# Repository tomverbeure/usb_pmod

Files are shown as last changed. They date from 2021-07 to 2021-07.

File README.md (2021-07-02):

# USB Combo PMOD

It's common to implement Full Speed or Low Speed (FS/LS) USB host or device controllers
on an FPGA by just using their digital IOs, configured as 3V3 LVCMOS. 

A good example is the [TinyFPGA BX board](https://www.adafruit.com/product/4038), 
which comes by default with a hardware-only USB device controller that's used to program new bitstreams into flash. 

Another one is [Fomu](https://www.crowdsupply.com/sutajio-kosagi/fomu), another FPGA development
board that's about as tiny as the USB Type-A connector itself.

However, on FPGAs such as those from the MAX10 family, this solution doesn't work: at
3V3, their IOs don't have the required driving strength. (Only 2mA for a 3V3 LVCMOS IO
on a MAX10.)

For those cases, the easiest FS/LS solution is to use an 
[STUSB03E PHY](https://www.st.com/en/interfaces-and-transceivers/stusb03e.html) for USB host or USB device.
It's a tiny little chip that translates regular digital signals as low as 1.6V to 
USB standard compliant signaling levels.

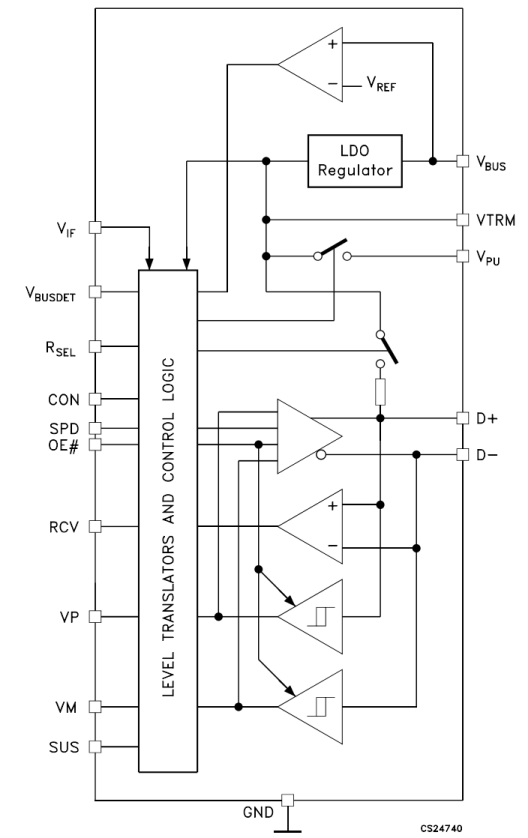
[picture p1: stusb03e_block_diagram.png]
STUSB03E Block Diagram


This project is a PMOD compatible module that contains an STUSB03E, 
the necessary passive components around it, as well as a USB Type-A or
USB Type-B connector footprint.

You need to decide up front whether to use PMOD for USB host or device
purposes, and change the soldered components accordingly.

It's a 4-layer PCB which is overkill, but there's currently no cost difference between
2 and 4 layer PCBs at [JLCPCB](https://jlcpcb.com), so I didn't spend any time to make
it work with 2 layers. It's definitely doable though!

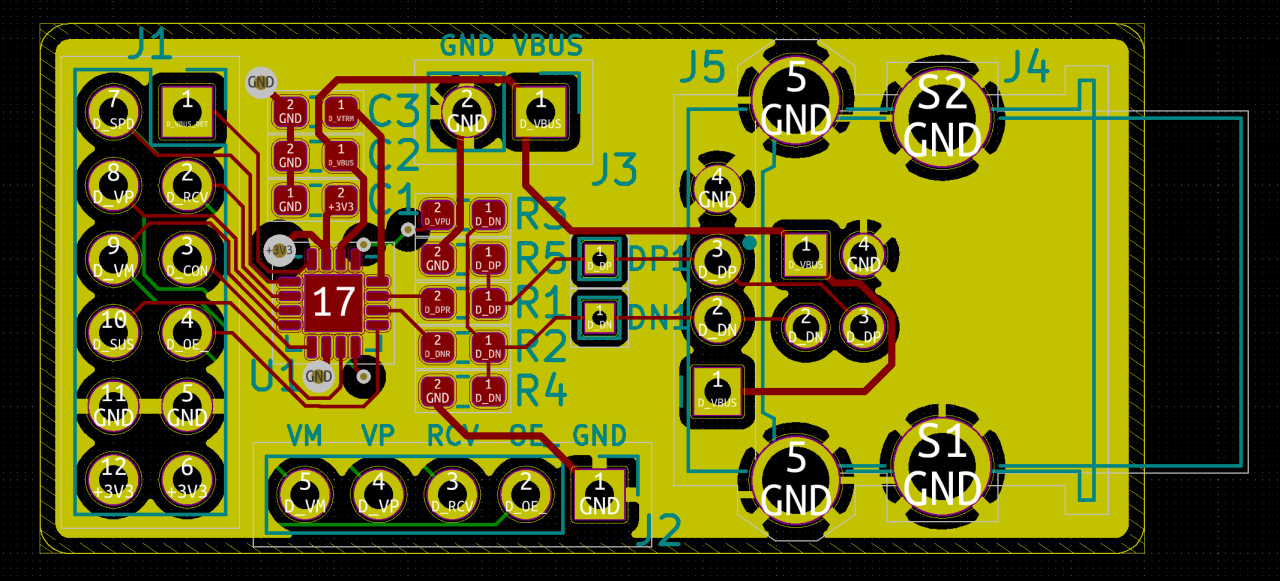
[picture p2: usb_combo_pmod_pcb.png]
USB Combo PMOD Layout


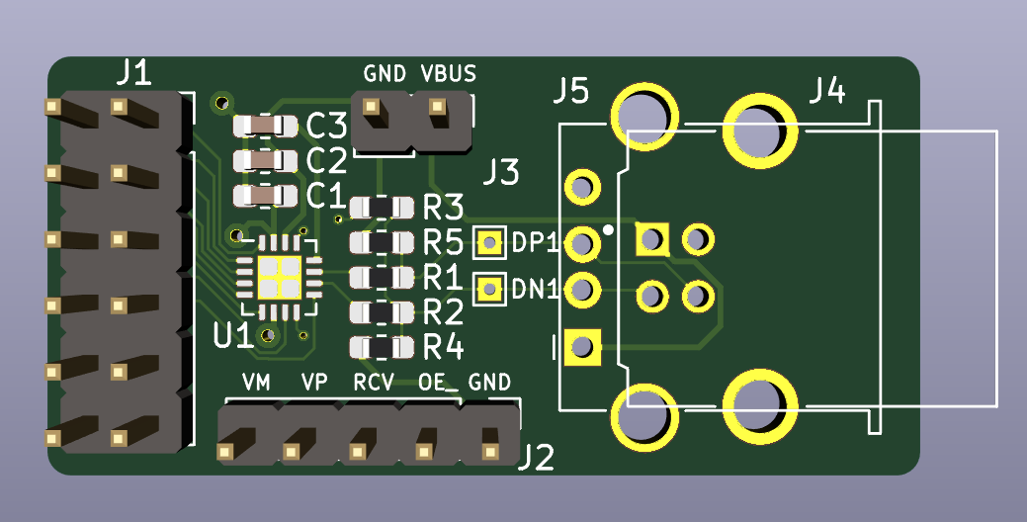
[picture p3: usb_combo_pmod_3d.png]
USB Combo PMOD 3D


## Instructions

Load the project with KiCAD, or check out a PDF of the schematic [here](./usb_combo_pmod_schematic.pdf)

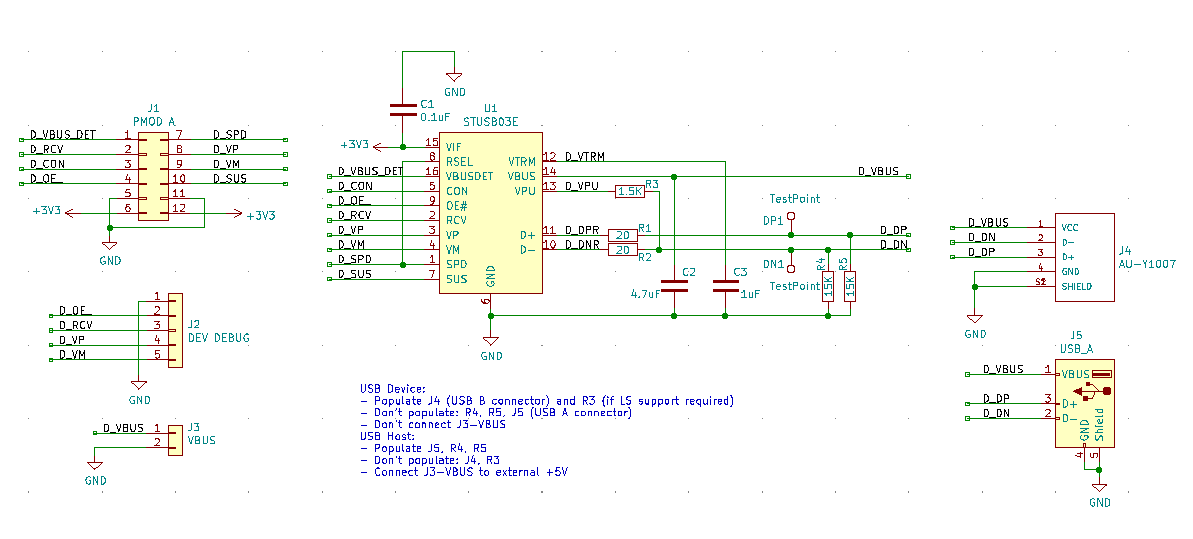
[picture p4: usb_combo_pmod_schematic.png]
USB Combo PMOD Schematic


Use a USB Device:

* Populate J4 (USB B connector) and R3 (if LS support required)
* Don't populate: R4, R5, J5 (USB A connector)
* Don't connect the J3-VBUS pin to anything! (The 5V will come from the USB cable.)

Use as USB Host:

* Populate J5, R4, R5
* Don't populate: J4, R3
* Connect the J3-VBUS pin to an external +5V supply

## BOM

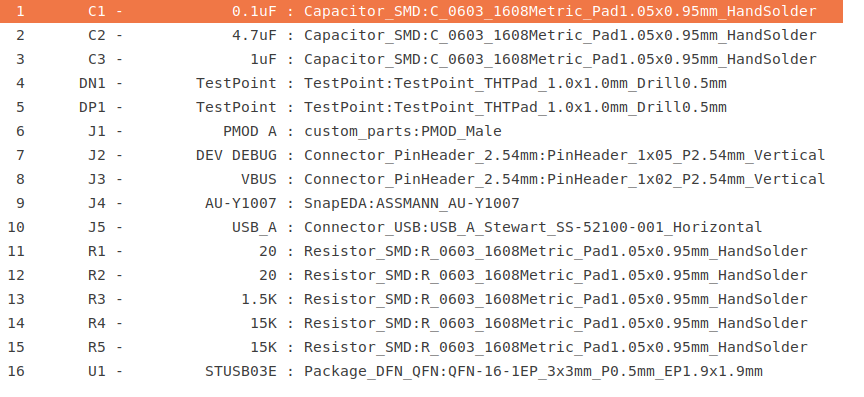
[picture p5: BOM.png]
BOM


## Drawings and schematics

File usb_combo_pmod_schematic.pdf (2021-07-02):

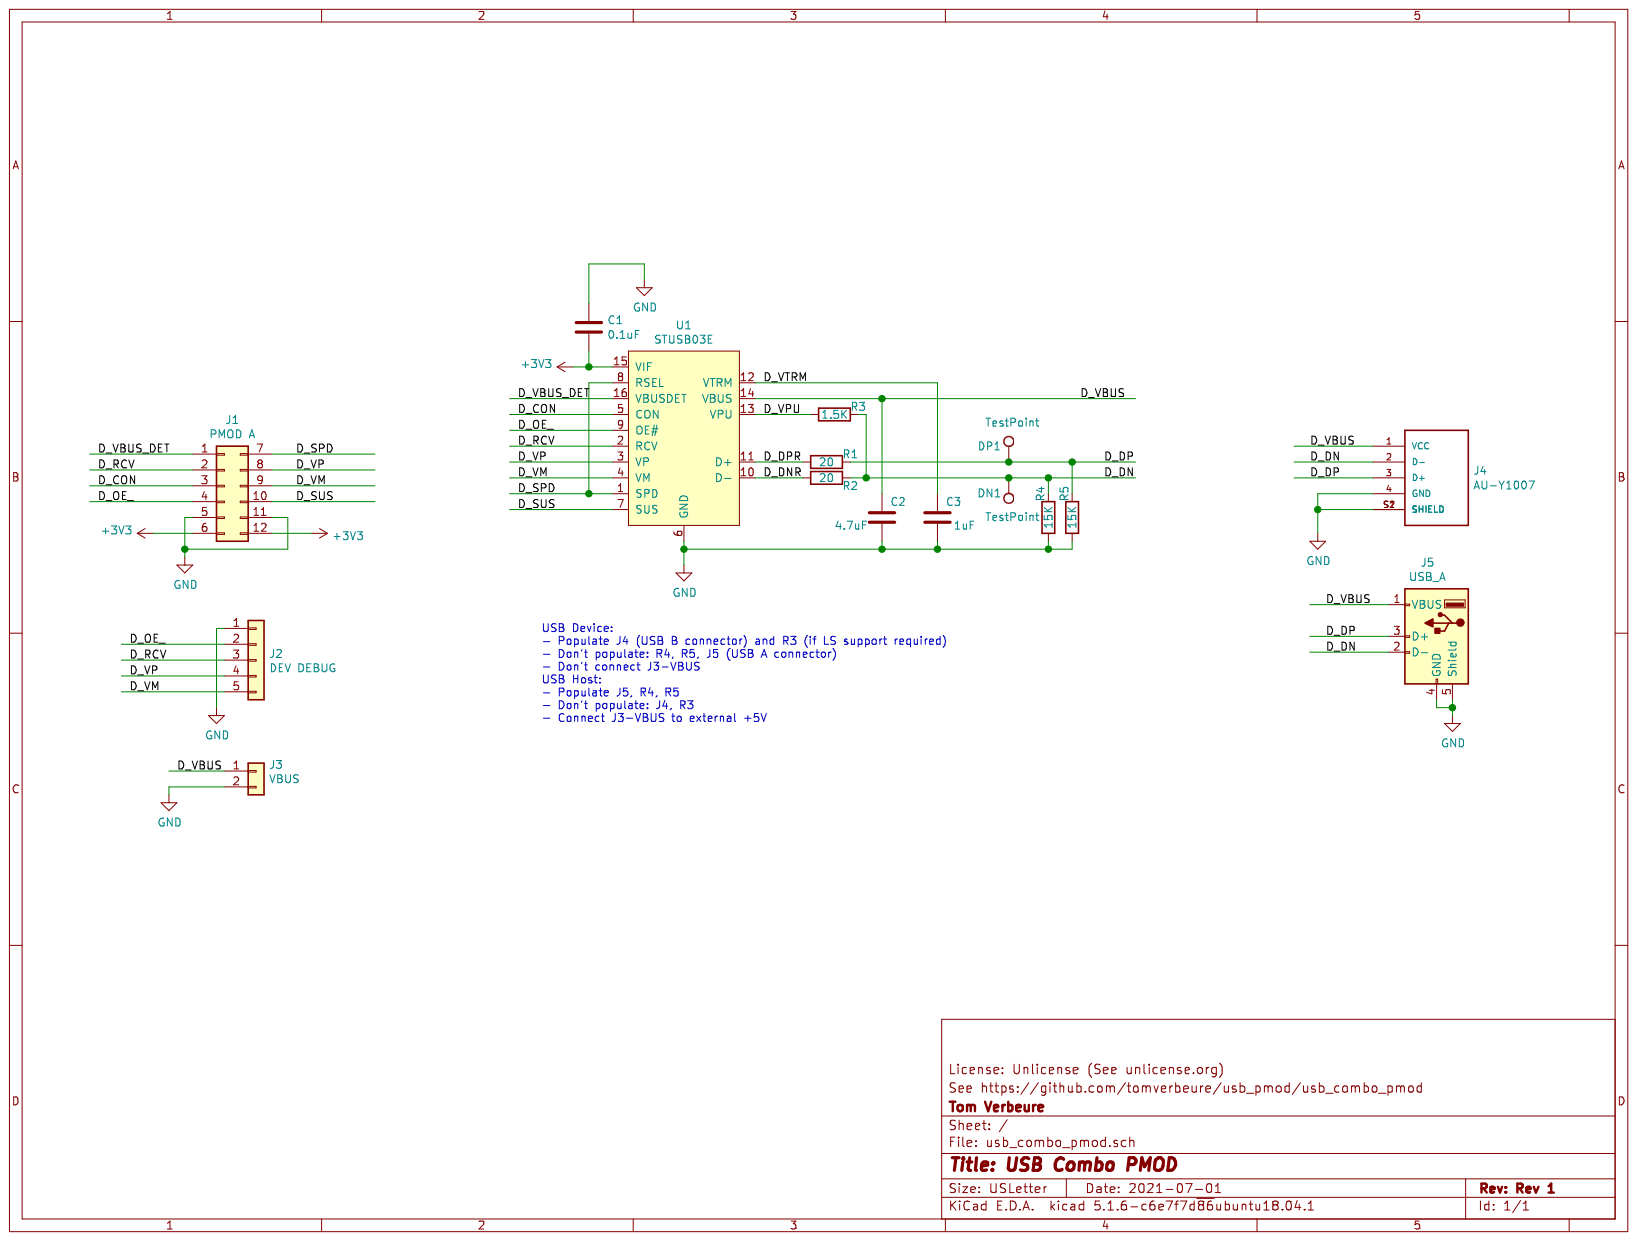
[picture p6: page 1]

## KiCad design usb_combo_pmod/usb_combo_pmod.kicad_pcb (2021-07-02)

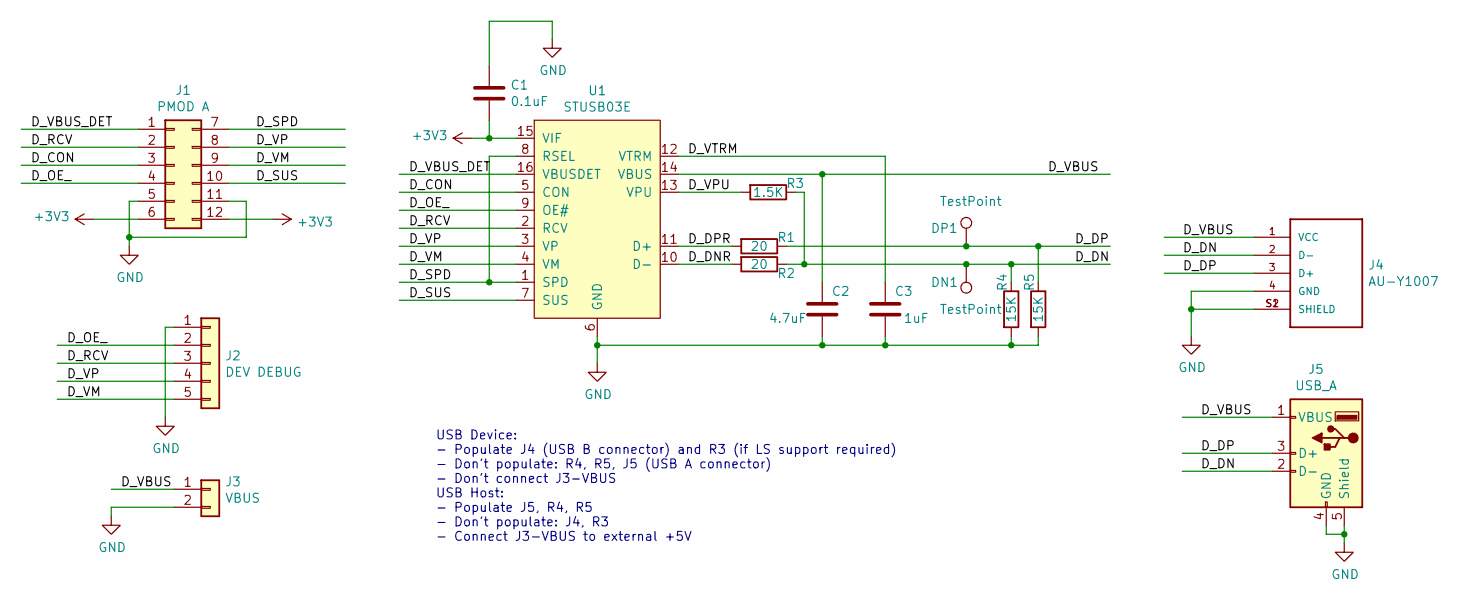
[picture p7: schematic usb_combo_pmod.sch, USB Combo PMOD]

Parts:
C1: 0.1uF; C_0603_1608Metric_Pad1.05x0.95mm_HandSolder
C2: 4.7uF; C_0603_1608Metric_Pad1.05x0.95mm_HandSolder
C3: 1uF; C_0603_1608Metric_Pad1.05x0.95mm_HandSolder
DN1: TestPoint; TestPoint_THTPad_1.0x1.0mm_Drill0.5mm
DP1: TestPoint; TestPoint_THTPad_1.0x1.0mm_Drill0.5mm
J1: PMOD A; PMOD_Male
J2: DEV DEBUG; PinHeader_1x05_P2.54mm_Vertical
J3: VBUS; PinHeader_1x02_P2.54mm_Vertical
J4: AU-Y1007; ASSMANN_AU-Y1007
J5: USB_A; USB_A_Stewart_SS-52100-001_Horizontal
R1, R2: 20; R_0603_1608Metric_Pad1.05x0.95mm_HandSolder
R3: 1.5K; R_0603_1608Metric_Pad1.05x0.95mm_HandSolder
R4, R5: 15K; R_0603_1608Metric_Pad1.05x0.95mm_HandSolder
U1: STUSB03E; QFN-16-1EP_3x3mm_P0.5mm_EP1.9x1.9mm

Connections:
+3V3: C1.2, J1.6, J1.12, U1.15 (VIF)
/D_CON: J1.3, U1.5 (CON)
/D_DN: DN1.1, J4.2 (D-), J5.2 (D-), R2.1, R3.1, R4.1
/D_DNR: R2.2, U1.10 (D-)
/D_DP: DP1.1, J4.3 (D+), J5.3 (D+), R1.1, R5.1
/D_DPR: R1.2, U1.11 (D+)
/D_OE_: J1.4, J2.2, U1.9 (OE#)
/D_RCV: J1.2, J2.3, U1.2 (RCV)
/D_SPD: J1.7, U1.1 (SPD), U1.8 (RSEL)
/D_SUS: J1.10, U1.7 (SUS)
/D_VBUS: C2.1, J3.1, J4.1 (VCC), J5.1 (VBUS), U1.14 (VBUS)
/D_VBUS_DET: J1.1, U1.16 (VBUSDET)
/D_VM: J1.9, J2.5, U1.4 (VM)
/D_VP: J1.8, J2.4, U1.3 (VP)
/D_VPU: R3.2, U1.13 (VPU)
/D_VTRM: C3.1, U1.12 (VTRM)
GND: C1.1, C2.2, C3.2, J1.5, J1.11, J2.1, J3.2, J4.4 (GND), J4.S1 (SHIELD), J4.S2 (SHIELD), J5.4 (GND), J5.5 (Shield), R4.2, R5.2, U1.6 (GND)

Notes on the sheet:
USB Device: - Populate J4 (USB B connector) and R3 (if LS support required) - Don't populate: R4, R5, J5 (USB A connector) - Don't connect J3-VBUS USB Host: - Populate J5, R4, R5 - Don't populate: J4, R3 - Connect J3-VBUS to external +5V

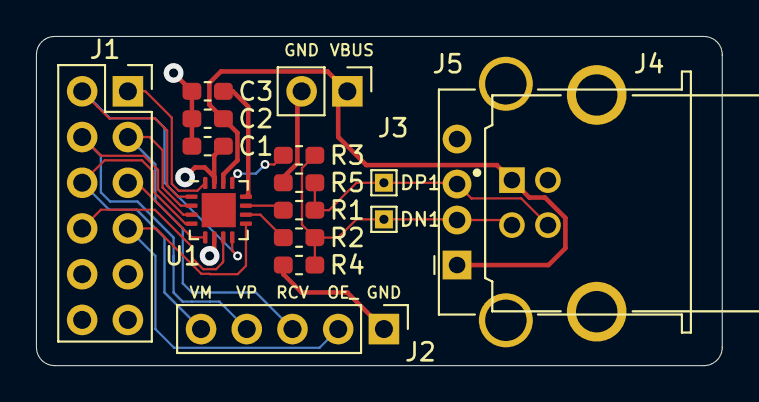
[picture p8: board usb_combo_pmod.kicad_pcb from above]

Board: 4 copper layers, 38.1 x 18.3 mm, 16 parts (0 on the bottom side), 17 nets.

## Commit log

2021-07-01 First version.
    [usb_dev_pmod-B_Cu.gbr, usb_dev_pmod-B_Mask.gbr, usb_dev_pmod-B_Paste.gbr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]
2021-07-01 Fix labels.
    [usb_dev_pmod.kicad_pcb, usb_host_pmod.kicad_pcb, usb_pmod.kicad_pcb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]
2021-07-02 USB Combo PMOD
    [usb_combo_pmod-B_Cu.gbr, usb_combo_pmod-B_Mask.gbr, usb_combo_pmod-B_Paste.gbr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]
2021-07-02 Add schematic image.

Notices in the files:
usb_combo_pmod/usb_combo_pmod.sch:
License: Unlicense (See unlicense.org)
